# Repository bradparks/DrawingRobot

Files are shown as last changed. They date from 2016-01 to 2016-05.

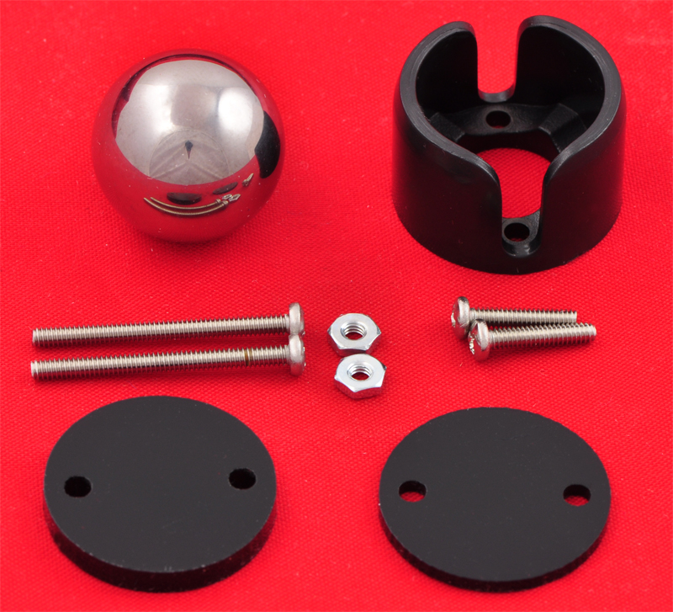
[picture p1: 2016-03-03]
OpenSCAD/pezzi/ballcaster/ball caster pololu 955.jpg

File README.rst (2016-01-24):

DrawingRobot
======


.. :scale: 50 %
.. :alt: DrawingRobot logo

Progetto per lo sviluppo di piccoli robot controllabili via bluetooth in grado di muoversi e disegnare sul piano in cui si muovono

`Overview <http://dev.hacklabterni.org/projects/drawrobot2015/>`_

`Wiki <http://dev.hacklabterni.org/projects/drawrobot2015/wiki>`_

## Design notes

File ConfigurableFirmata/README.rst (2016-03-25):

ConfigurableFirmata
======

`ConfigurableFirmata LastVersion <https://github.com/hacklabterni/ConfigurableFirmata>`_

`ConfigurableFirmata Tested <http://dev.hacklabterni.org/attachments/download/1256/ConfigurableFirmata-master.zip>`_

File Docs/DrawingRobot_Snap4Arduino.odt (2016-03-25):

Importare il progetto tramite la voce di menù Import:

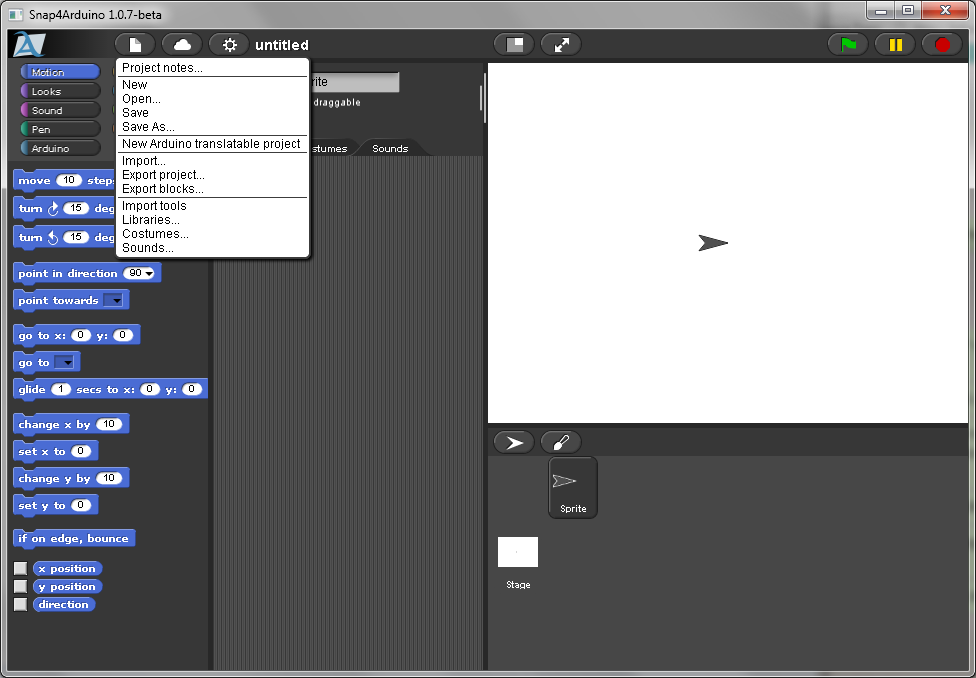
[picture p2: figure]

Selezionando l'ultima versione presente su GitHub: https://github.com/hacklabterni/DrawingRobot/blob/master/Snap4Arduino/DrawingRobot.xml

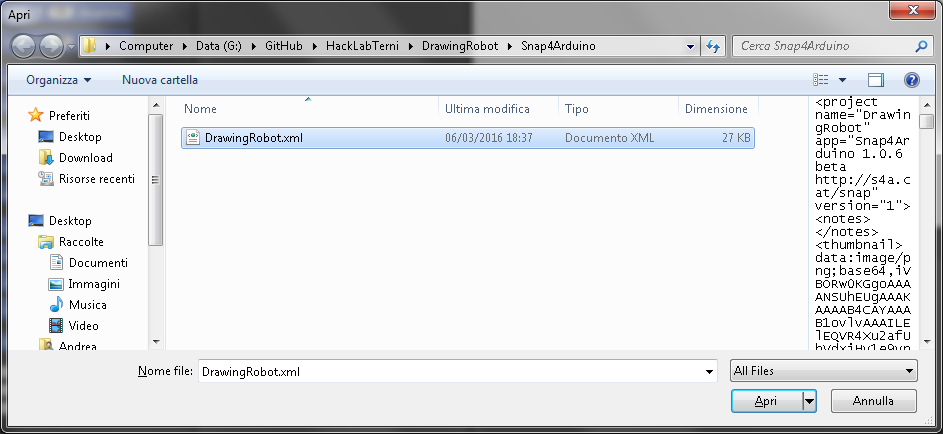
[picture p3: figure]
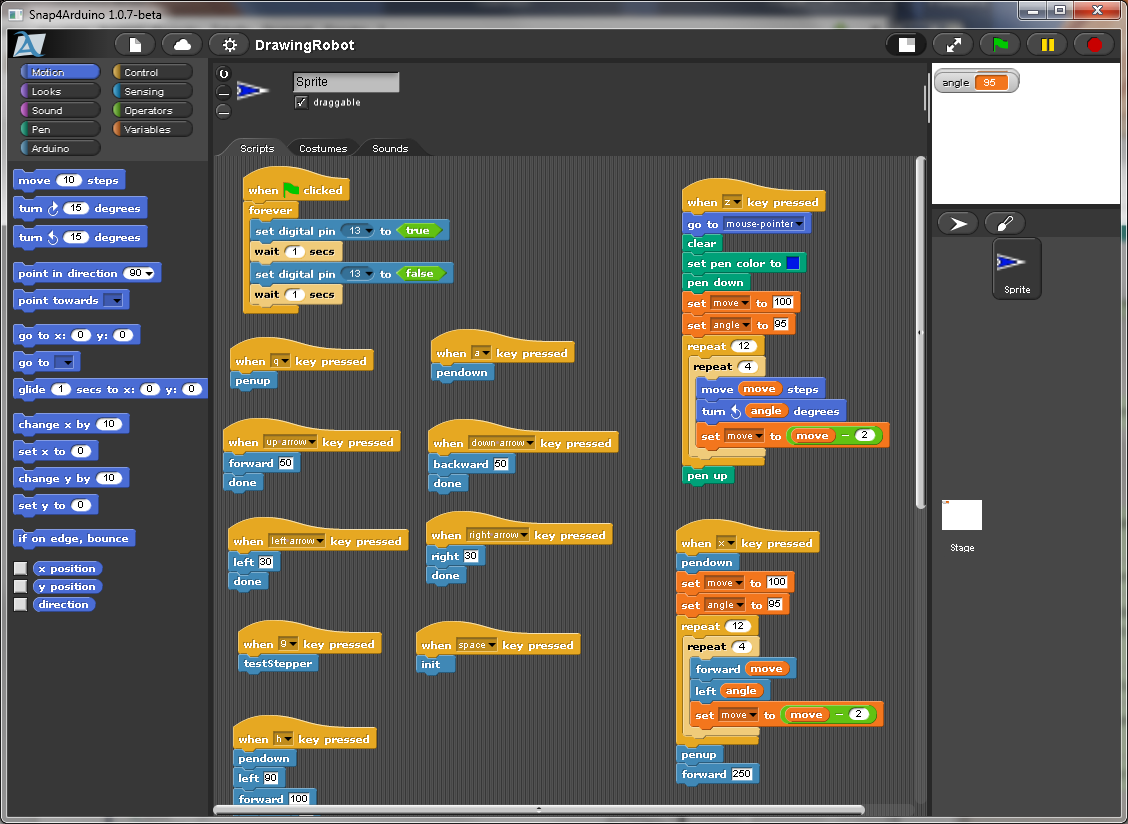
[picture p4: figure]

Se il processo di importazione è avvenuto correttamente si otterrà la seguente schermata:

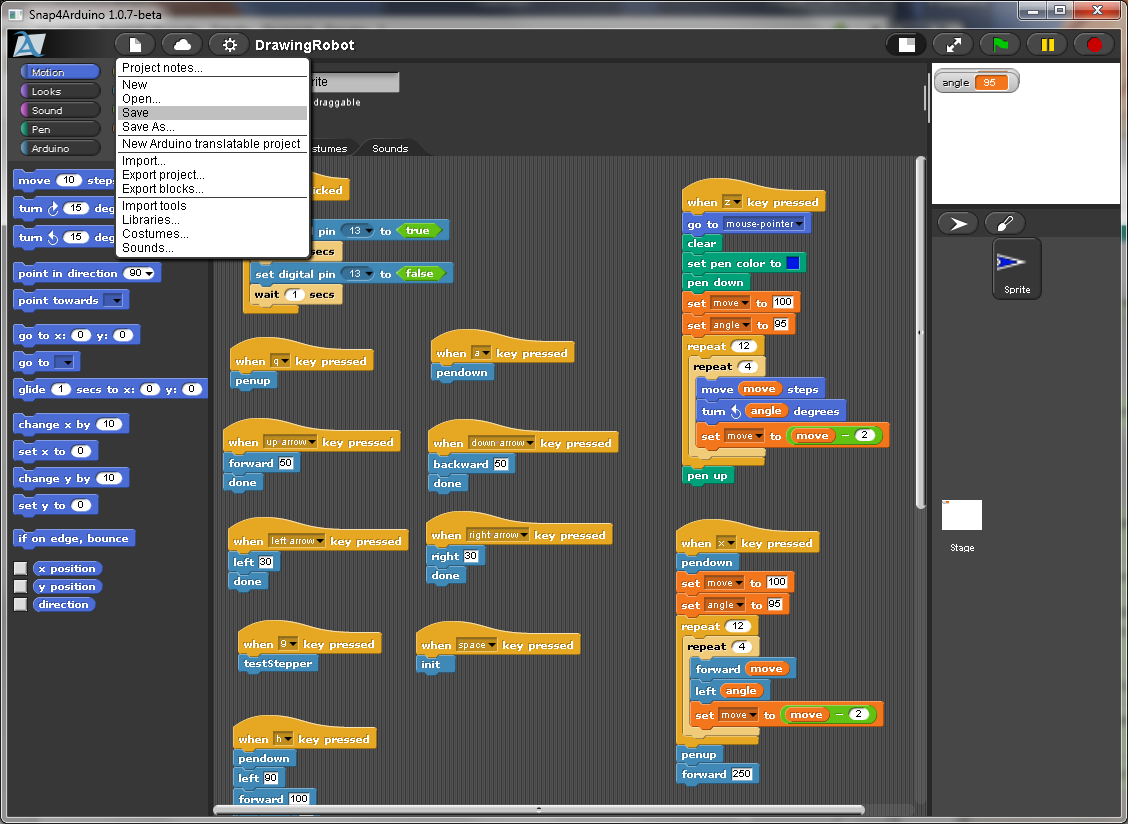
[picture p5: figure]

Salvare il progetto tramite la voce di menù Save, in questo modo si potrà riaprire il progetto stesso tramite Open (senza ripetere l'operazione precedente di import)

Spostarsi nei blocchi di Arduino

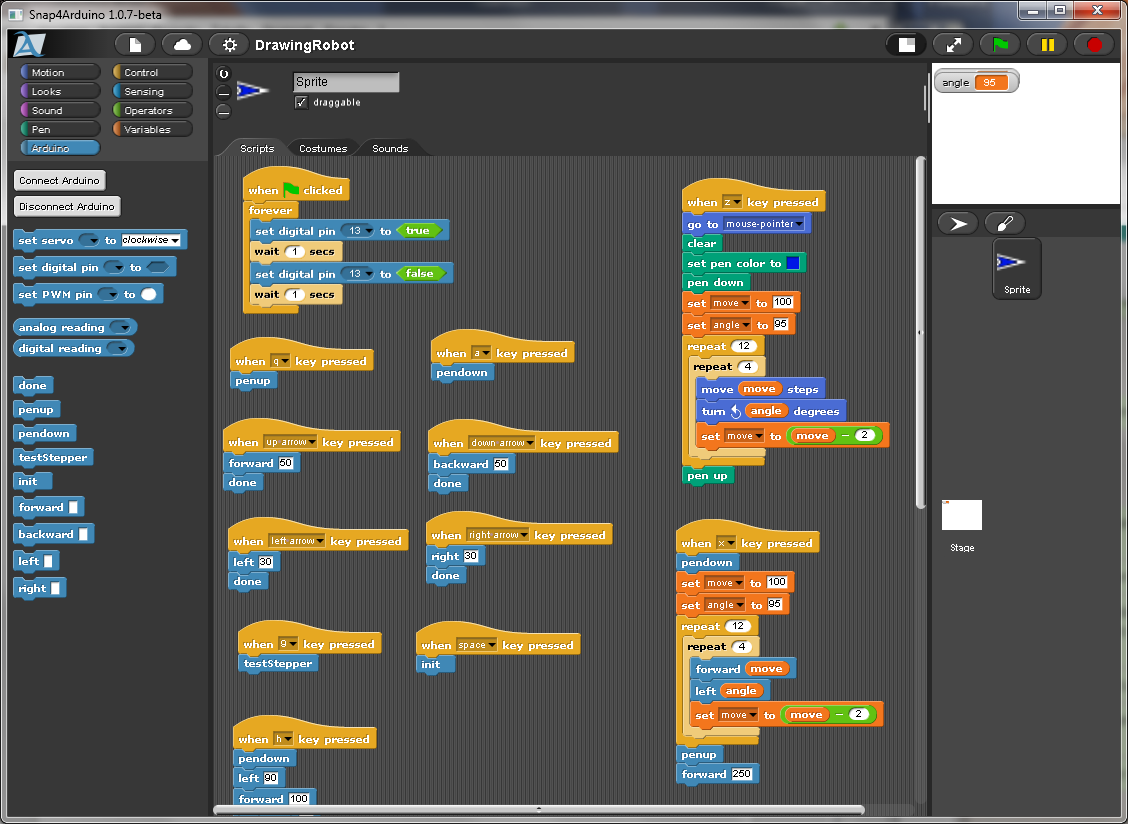
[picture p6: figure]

Premere il pulsante Connect Arduino selezionando la porta corretta

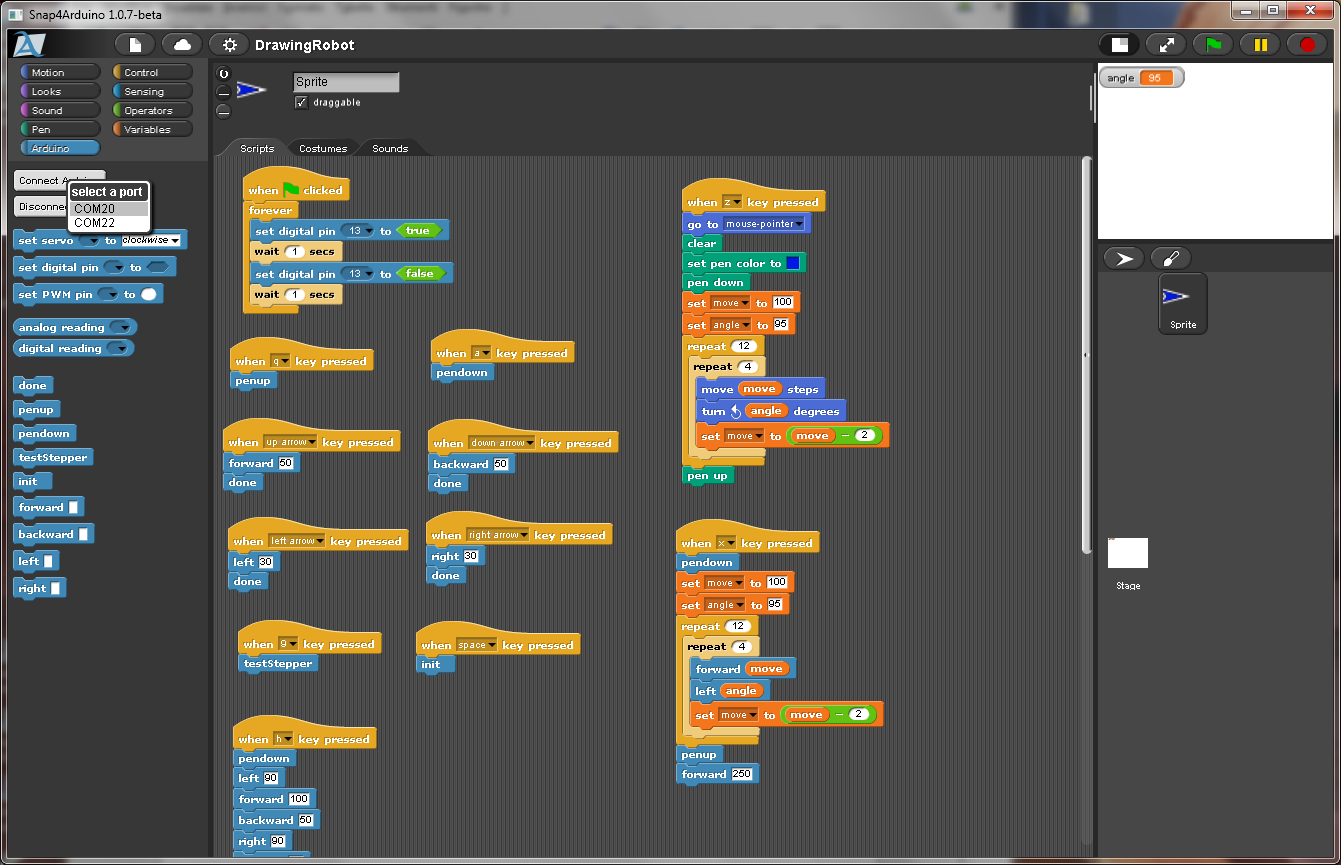
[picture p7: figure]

Attendere l'instaurarsi della connessione

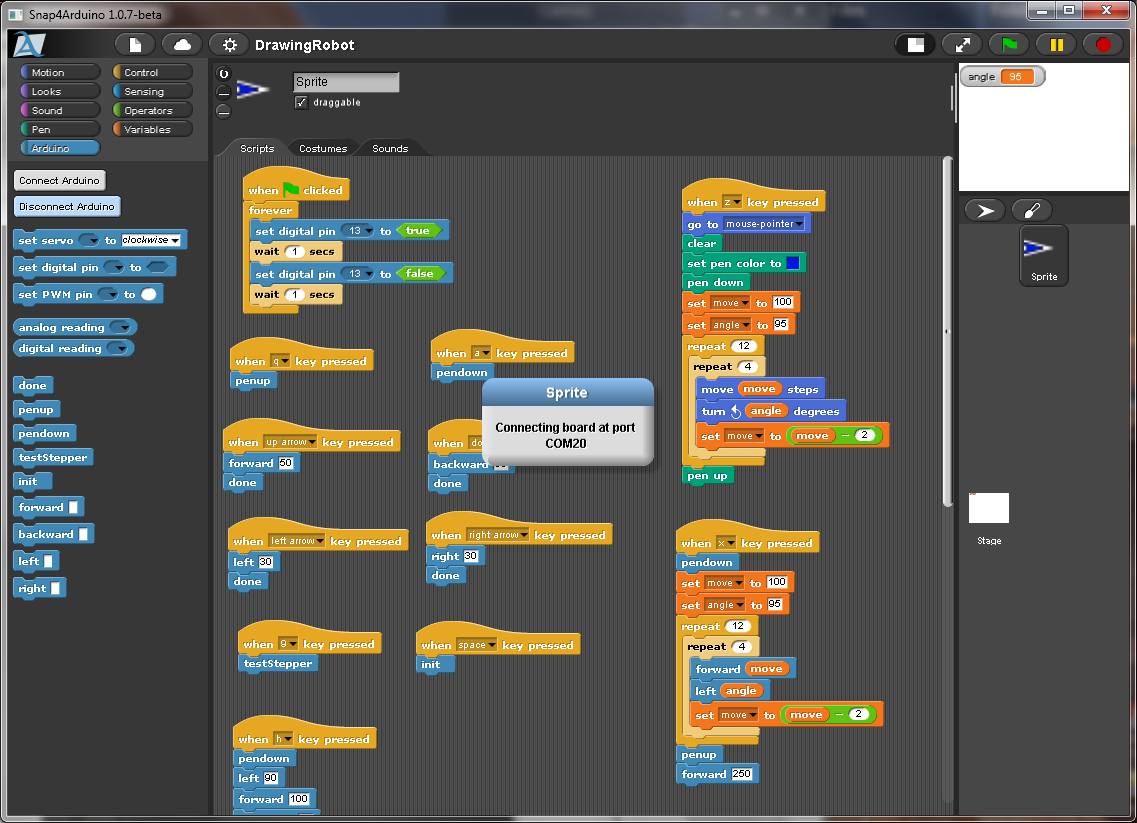
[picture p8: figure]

Connessione avvenuta con successo, il Drawing Robot è ai vostri comandi

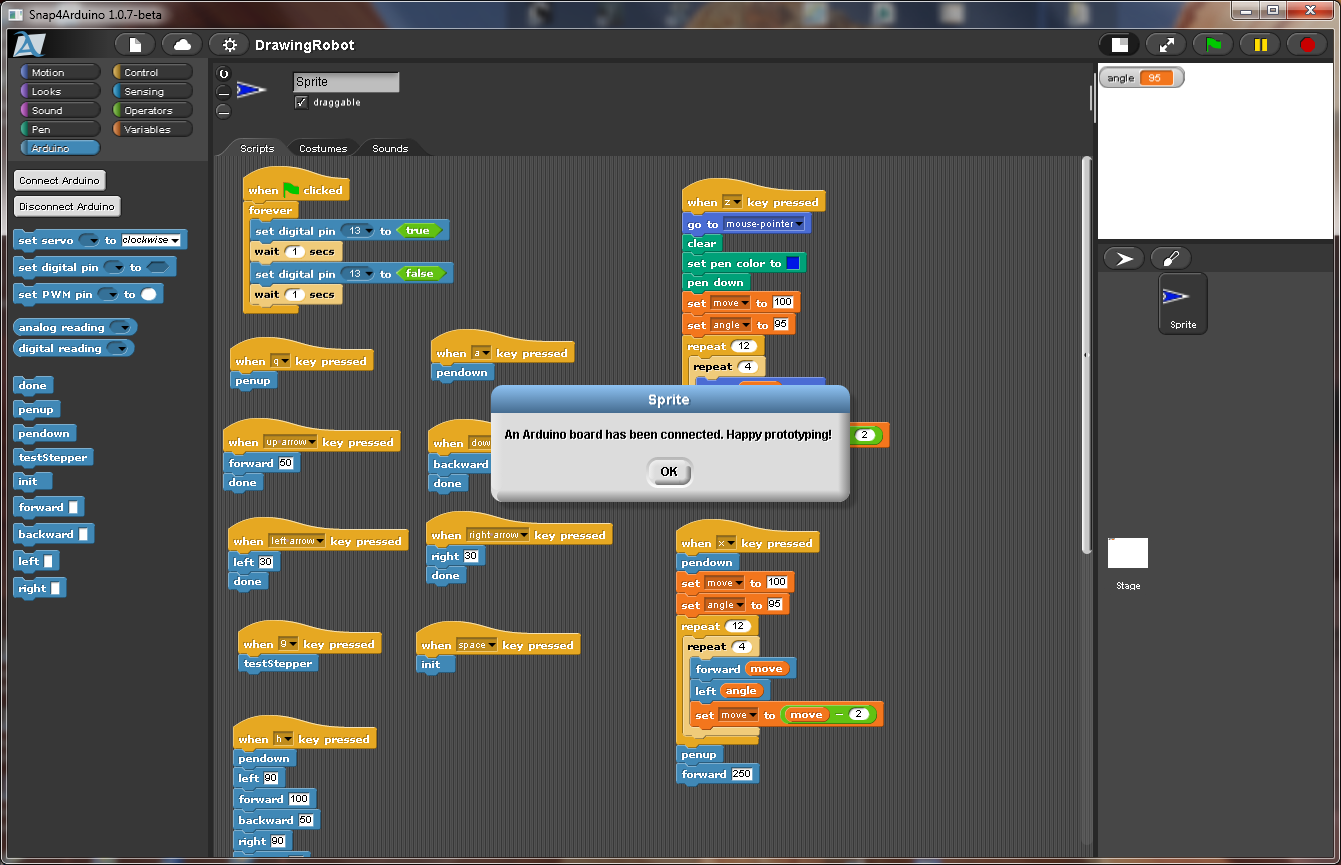
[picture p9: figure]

Come prima cosa occorre eseguire il blocco init di inizializzazione tramite il tasto space della tastiera.

Da questo momento si possono inviare tutti i seguenti comandi al Drawing Robot:

1. penup
2. pendown
3. forward (x)
4. backward (x)
5. left (a)
6. right (a)
7. done

dove la x è espressa in mm e la a in gradi

Importante alla fine di ogni insieme di comandi è consigliabile far eseguire il blocco done che ha la funzione di sbloccare i motori.

Note: Non instaurare la connessione con Arduino se prima non si è caricato/importato il programma DrawingRobot in Snap4Arduino

Troubleshooting:

1. Connect Arduino non instaura correttamente la connesione:
  a. Assicurarsi di aver eseguito il pairing con il bluetooth
  b. Provare altra porta
  c. Riavviare il DrawingRobot (tramite apposito interruttore) e poi chiudere e riaprire il programma Snap4Arduino

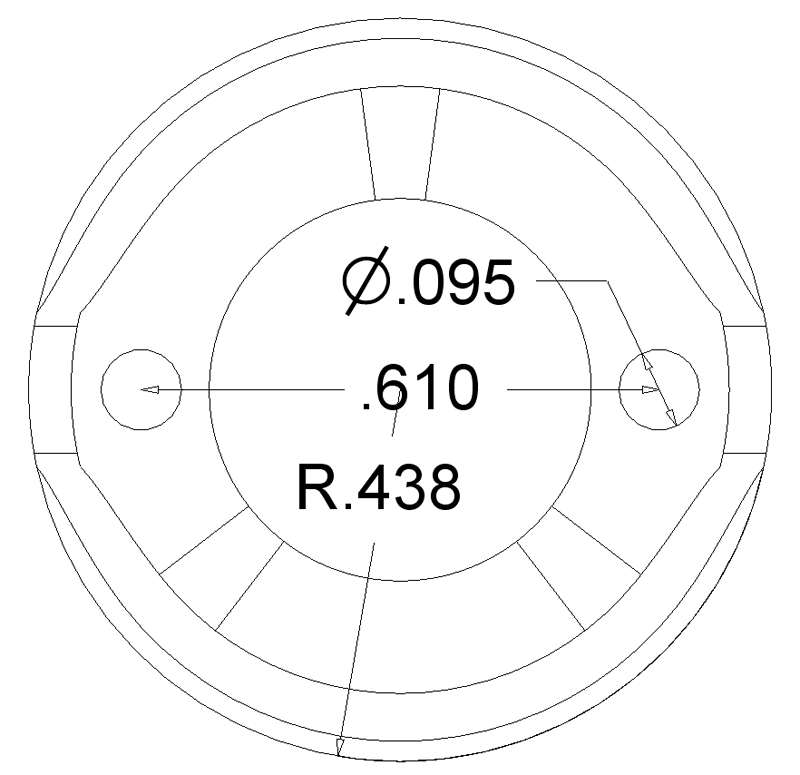
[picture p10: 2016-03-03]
OpenSCAD/pezzi/ballcaster/ball caster pololu 955 misure2.jpg

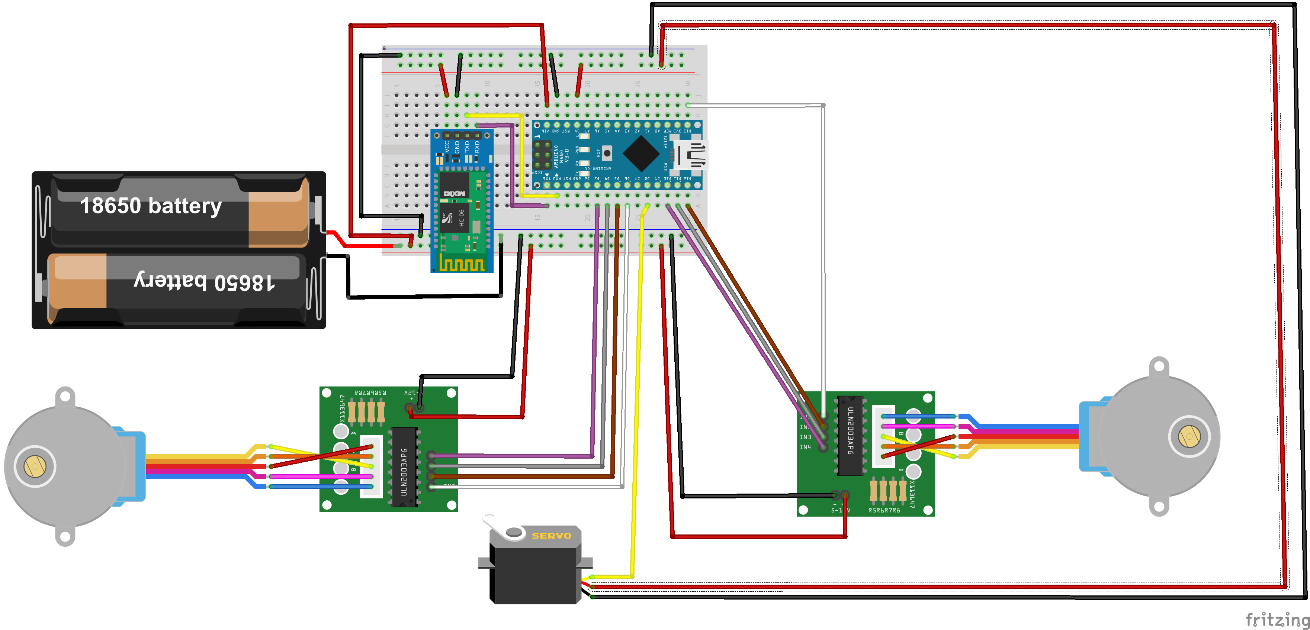
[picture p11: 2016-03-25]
Fritzing/DrawingRobot_2x18650_bb.png

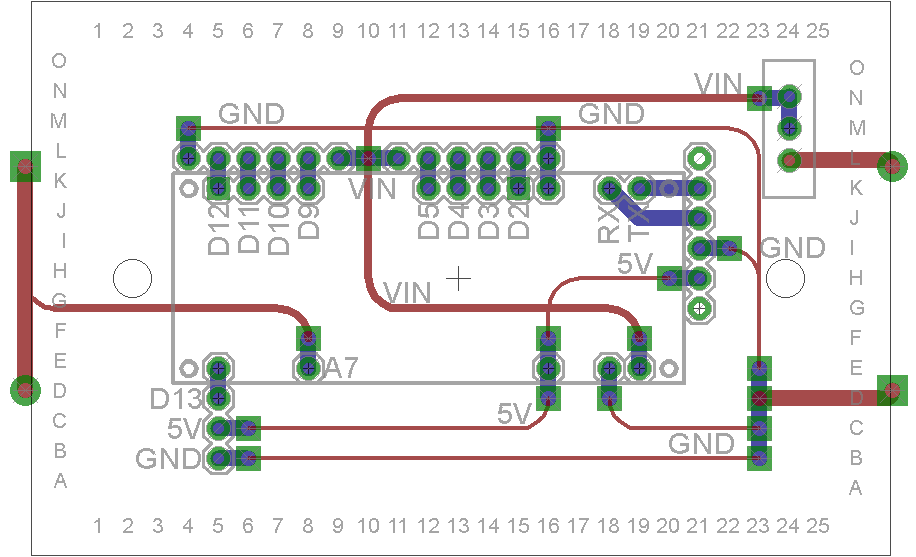
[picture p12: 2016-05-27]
Eagle/millefori.png

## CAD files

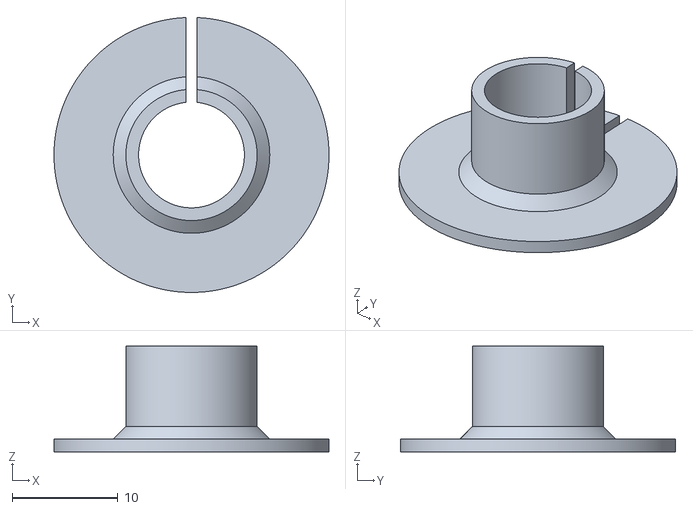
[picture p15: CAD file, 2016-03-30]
da stampare/Pen_Collar2.stl
26.0 x 26.0 x 10.0

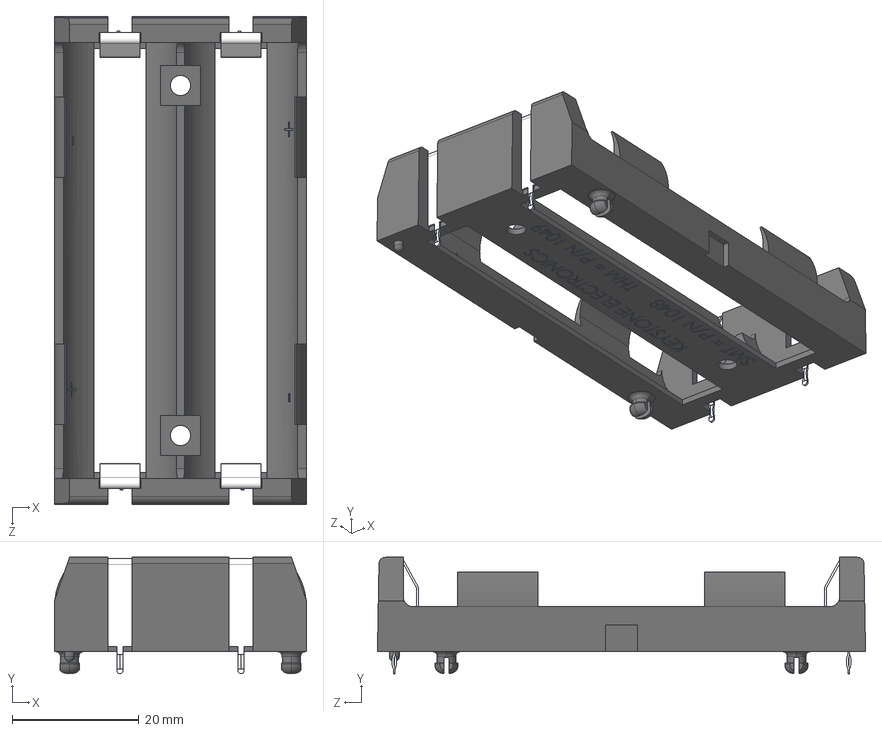
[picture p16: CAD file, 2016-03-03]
OpenSCAD/pezzi/elettronica/batt/keystone-PN1049.stp
39.8 x 18.4 x 77.1 mm

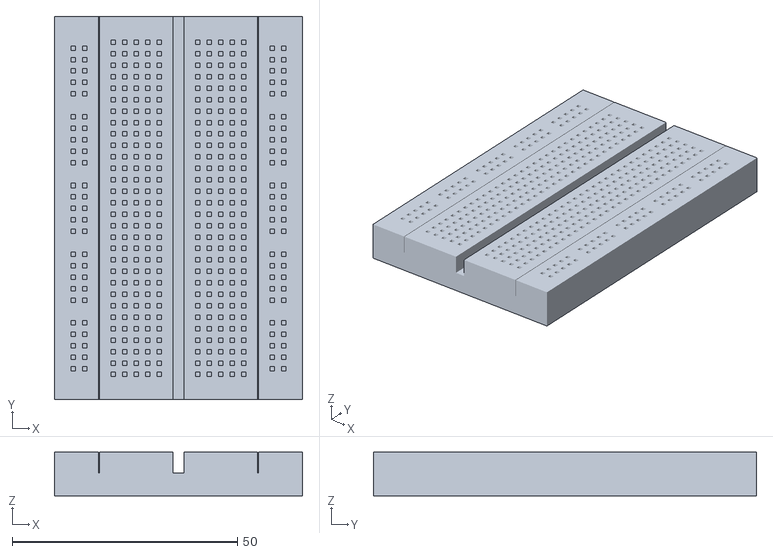
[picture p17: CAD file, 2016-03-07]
OpenSCAD/pezzi/protoboard.stl
55.0 x 85.0 x 9.70

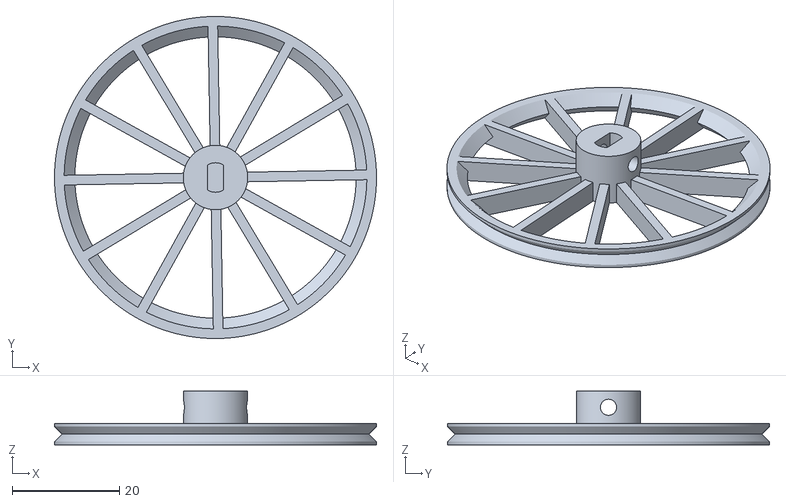
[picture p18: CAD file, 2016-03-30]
da stampare/12wheelNew.stl
60.0 x 60.0 x 10.0

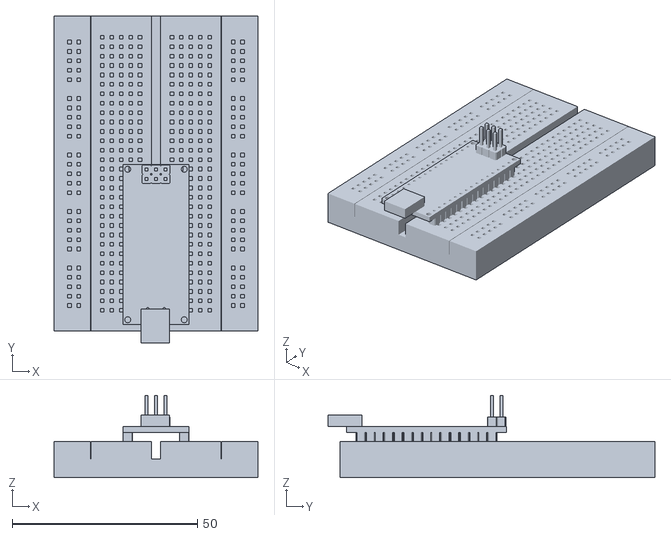
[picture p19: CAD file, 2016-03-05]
OpenSCAD/pezzi/protoboard/protoboard_Arduino.stl
55.0 x 88.3 x 22.2

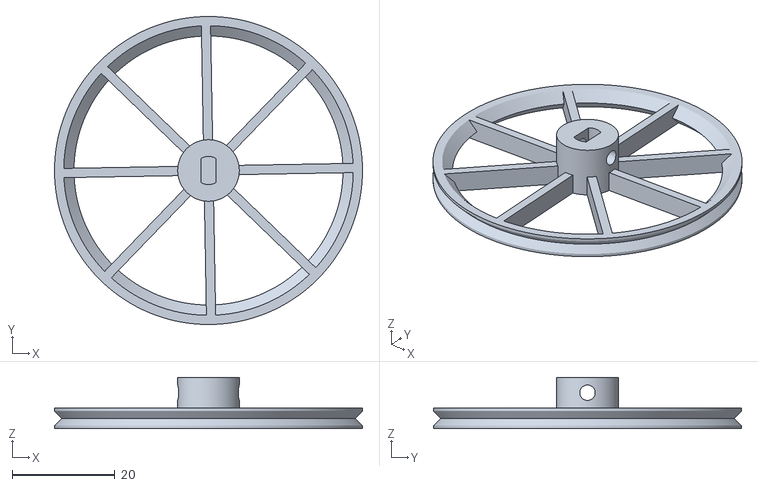
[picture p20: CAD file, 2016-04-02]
OpenSCAD/ruota8raggi.stl
60.0 x 60.0 x 10.0

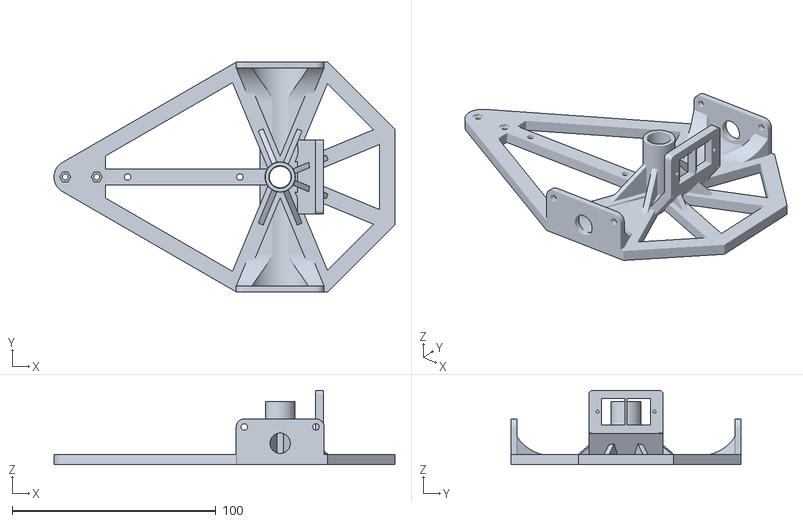
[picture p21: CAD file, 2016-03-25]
OpenSCAD/ottagono_triangolo_barreUguali.stl
167.5 x 112.9 x 36.5

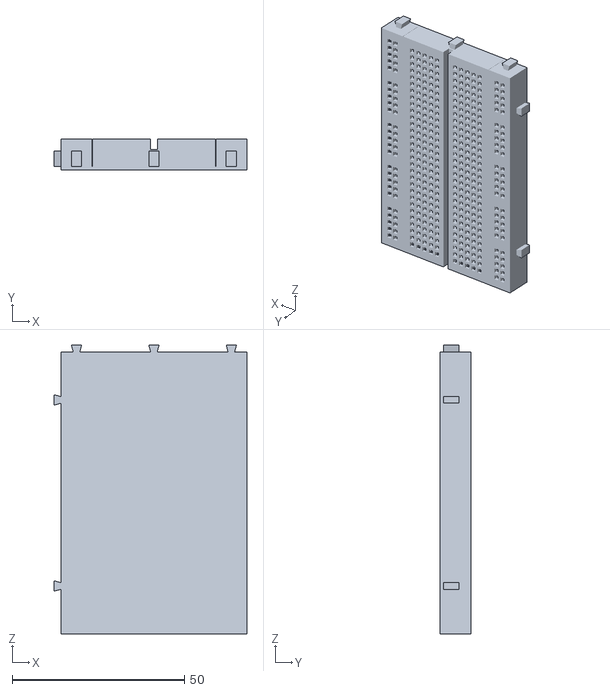
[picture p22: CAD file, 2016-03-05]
OpenSCAD/pezzi/protoboard/OLDprotoboard.stl
56.0 x 9.00 x 84.0

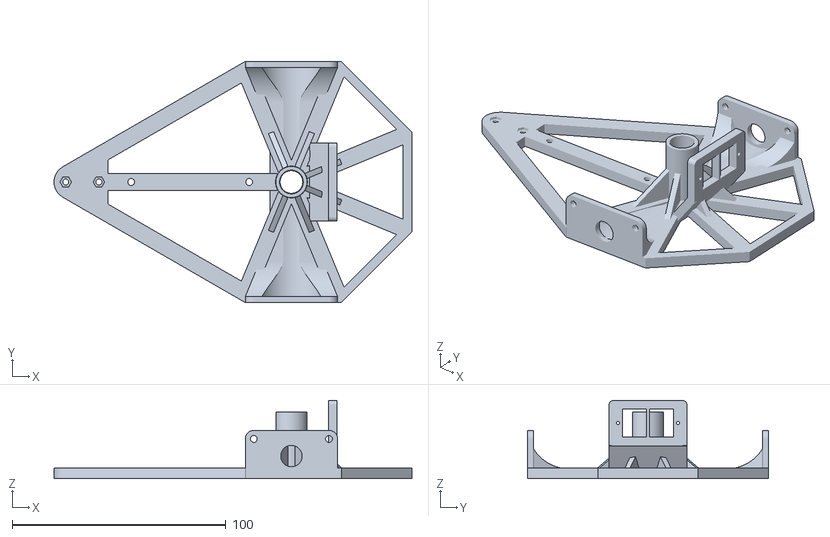
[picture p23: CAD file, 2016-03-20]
OpenSCAD/ottagono_triangoloSmussato.stl
167.5 x 112.9 x 36.5

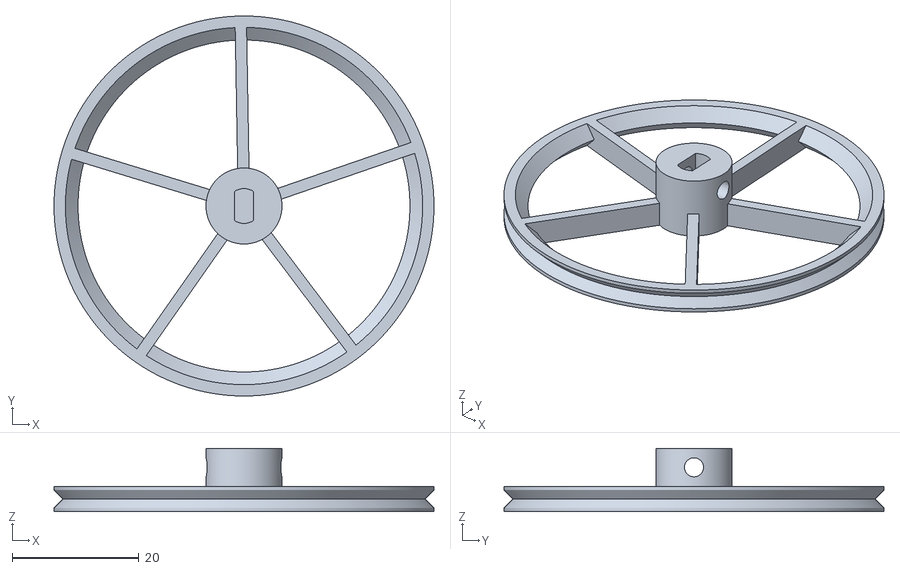
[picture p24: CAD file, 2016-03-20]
OpenSCAD/ruota5raggi.stl
60.0 x 60.0 x 10.0

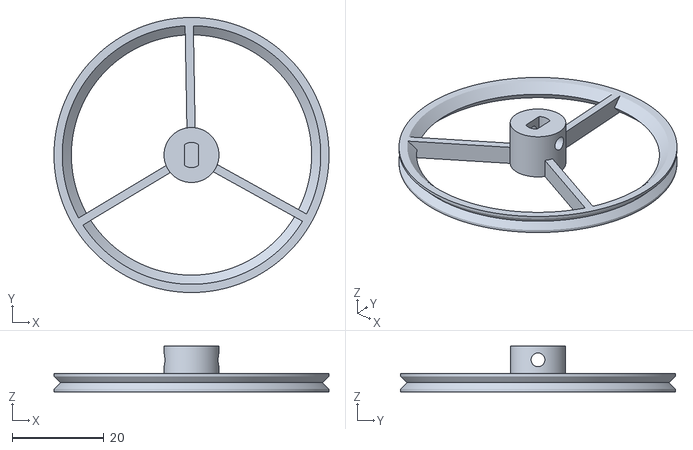
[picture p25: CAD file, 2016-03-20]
OpenSCAD/ruota3raggi.stl
60.0 x 60.0 x 10.0

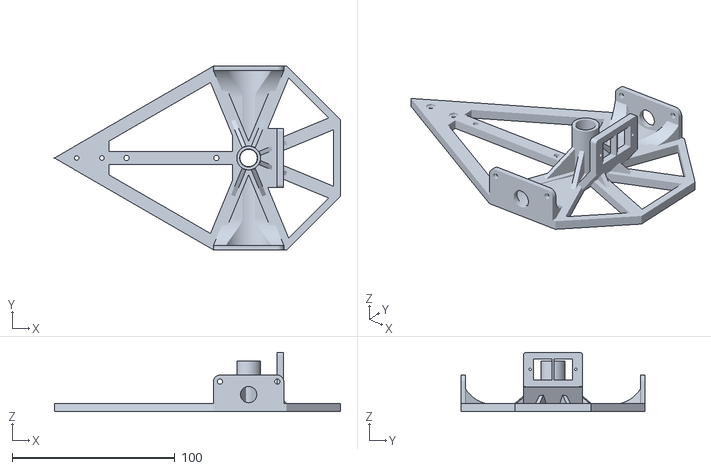
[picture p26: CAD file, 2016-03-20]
OpenSCAD/ottagono_triangolo.stl
175.6 x 112.9 x 36.5

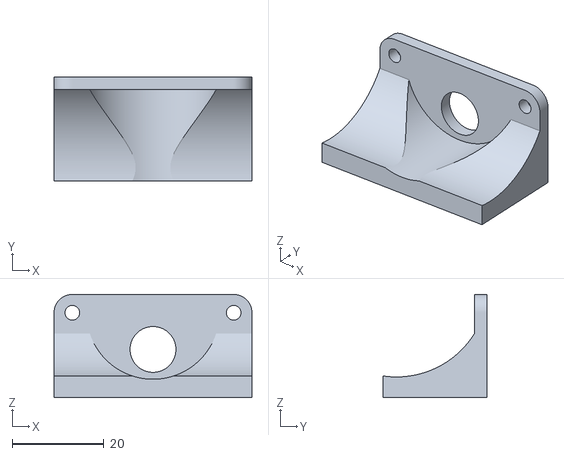
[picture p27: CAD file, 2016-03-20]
OpenSCAD/ruota_motore2.stl
43.2 x 22.8 x 22.5

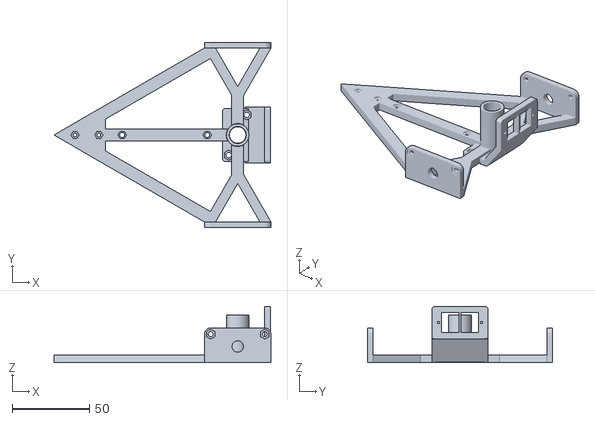
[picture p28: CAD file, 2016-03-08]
OpenSCAD/union_stampabile_servo_da_mod.stl
140.8 x 120.0 x 36.5

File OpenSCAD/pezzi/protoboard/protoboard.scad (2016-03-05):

mx=[[1,0,0],[0,0,0]]; //mirror X
x=55;
y=85;
z=9.7;
passo=2.54;

difference() {
    translate([-x/2,0,0]) cube([x,y,z]);
    union() {
        translate([-passo/2,0,passo*2]) cube([passo,y,z-passo*2]);
        for (i=mx) mirror(i) {
            translate([x/2-10,0,passo*2]) cube([0.2,y,z-passo*2]);
            for(a=[1:1:5], b=[1:1:30]) translate([a*passo+passo/2,b*passo+passo,passo*2]) cube([1,1,z-passo*2]);
            for(a1=[8,9], b1=[1,2,3,4,5, 7,8,9,10,11, 13,14,15,16,17, 19,20,21,22,23, 25,26,27,28,29]) translate([a1*passo,b1*passo+passo*3/2,passo*2]) cube([1,1,z-passo*2]);
        }
    }
}

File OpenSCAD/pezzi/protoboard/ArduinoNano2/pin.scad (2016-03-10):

module pin(n){
    millis= 0.0254;
    pin=    30*millis;
    pinH=   450*millis;
    space=  100*millis;
    cut=    10*millis;
    mXY=[   [0,0,0], 
            [0,1,0],
            [1,0,0],
            [1,1,0]]; //mirror XY
for (x=[0:1:n-1], y=[0:1:0]) translate([x*2.54,y*2.54,0]) {
   
    color("gold")
    translate ([-pin/2,-pin/2,-120*millis]) cube([pin,pin,pinH]);    
    color("gray") 
    difference(){
        translate(-[space,space]/2) cube([space,space,space]);
//        for (i=mXY) mirror(i) translate([space,space]/2)cylinder(space,cut,cut,$fn=8);
    }
}
}
pin(10);

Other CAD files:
OpenSCAD/Pen_Collar2.stl
OpenSCAD/pezzi/protoboard/protoboard.stl
OpenSCAD/pezzi/elettronica/batt/batt.stl
OpenSCAD/pezzi/protoboard/protoboard_light.scad
OpenSCAD/pezzi/protoboard/ArduinoNano2/pinF.scad
OpenSCAD/Chassis_Trinket.scad
OpenSCAD/Pen_Holder2.scad
OpenSCAD/Stepper_Bracket2.scad
OpenSCAD/Tutto_Michele.scad
OpenSCAD/cuore.scad
OpenSCAD/hexagon.scad
OpenSCAD/ottagono_triangolo.scad
OpenSCAD/pezzi/ballcaster/ballcaster.scad
OpenSCAD/pezzi/batt_electronics.scad
OpenSCAD/pezzi/elettronica/ArduinoNanoXY/ArduinoNanoXY.scad
OpenSCAD/pezzi/elettronica/ArduinoNanoXY/pinFxy.scad
OpenSCAD/pezzi/elettronica/ArduinoNanoXY/pinMxy.scad
OpenSCAD/pezzi/elettronica/elettronica.scad
OpenSCAD/pezzi/protoboard/ArduinoNano/pin.scad
OpenSCAD/pezzi/protoboard/ArduinoNano/pinF.scad
OpenSCAD/pezzi/protoboard/ArduinoNano2/ArduinoNano.scad
OpenSCAD/pezzi/protoboard/MILLEFORI.scad
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

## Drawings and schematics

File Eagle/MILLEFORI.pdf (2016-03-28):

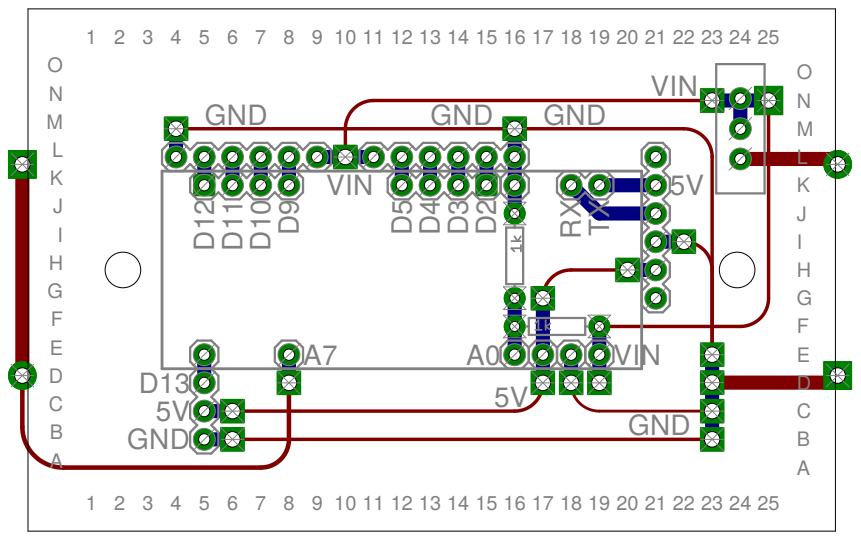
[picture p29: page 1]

D12 D13 TXRXD2 D3 D4 D5 D9 D10 D11 GND VIN 5V A7 A05V VIN GND5V GND GND GND VIN 1 2 3 4 5 6 7 8 9 10 11 12 13 14 15 16 17 18 19 20 21 22 23 24 25 HGFEDCBAONMLKJI HGFEDCBAONMLKJI 1 2 3 4 5 6 7 8 9 10 11 12 13 14 15 16 17 18 19 20 21 22 23 24 25

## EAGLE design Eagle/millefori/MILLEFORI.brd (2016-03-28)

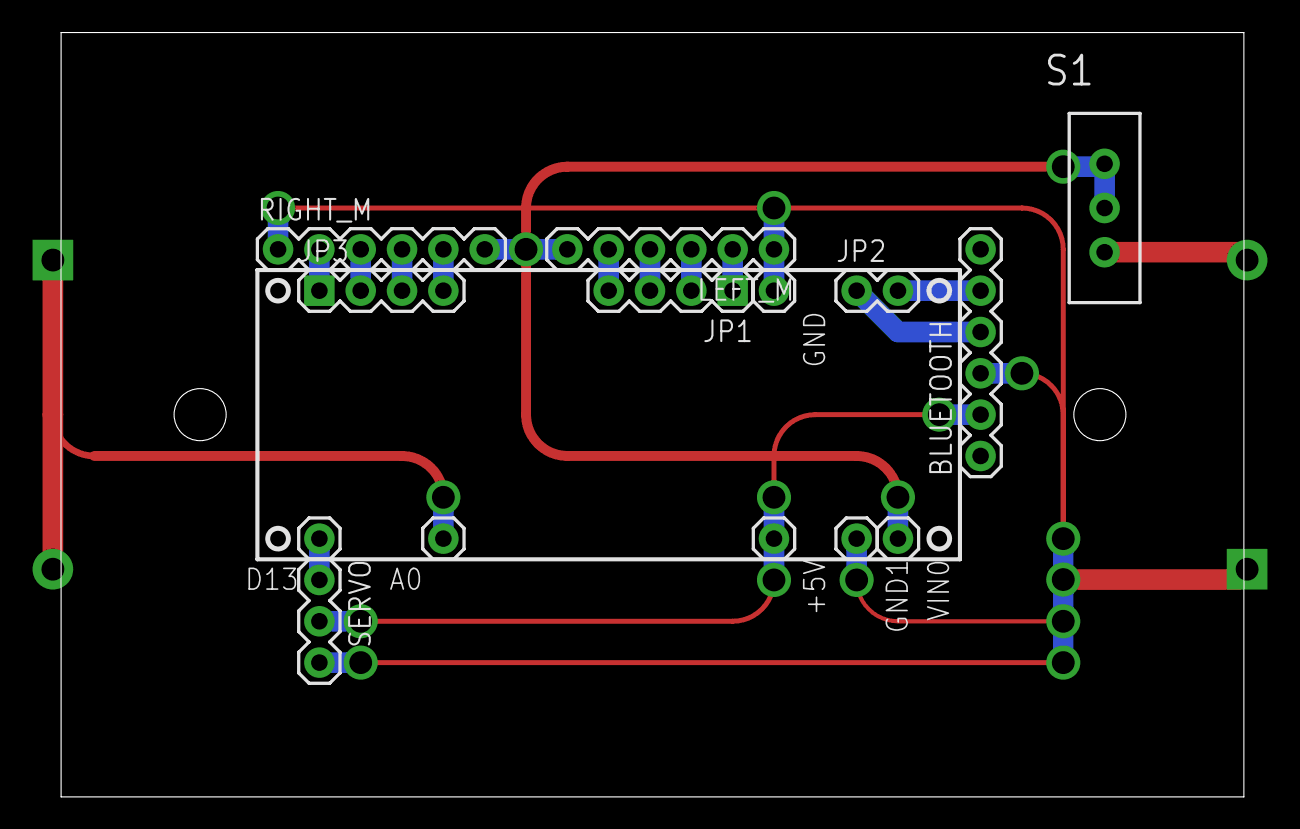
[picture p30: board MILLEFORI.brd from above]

Board: 2 copper layers, 72.7 x 47.0 mm, 15 parts (0 on the bottom side), 16 nets.

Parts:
+5V: 1X01
A0: 1X01
BLUETOOTH: 1X06
D13: 1X01
GND, GND1: 1X01
JP1, JP3: 1X04
JP2: 1X02
LEFT_M: 1X06
RIGHT_M: 1X06
S1: SWITCH-SPDT_LOCK.007S
SERVO: 1X03
U$3: 18650; BATTERY_PACK_18650
VIN0: 1X01

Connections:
+5V: +5V.1, BLUETOOTH.2, SERVO.2
+7,2V: S1.3, U$3.+3.7V_1
A0: A0.1, U$3.+3.7V_2, U$3.GND_1
D0/RX: BLUETOOTH.5, JP2.2
D1/TX: BLUETOOTH.4, JP2.1
D2: JP1.1, LEFT_M.2
D3: JP1.2, LEFT_M.3
D4: JP1.3, LEFT_M.4
D5: JP1.4, LEFT_M.5
D9: JP3.1, RIGHT_M.2
D10: JP3.2, RIGHT_M.3
D11: JP3.3, RIGHT_M.4
D12: JP3.4, RIGHT_M.5
D13: D13.1, SERVO.1
GND: BLUETOOTH.3, GND.1, GND1.1, LEFT_M.1, RIGHT_M.1, SERVO.3, U$3.GND_2
VIN: LEFT_M.6, RIGHT_M.6, S1.1, S1.2, VIN0.1

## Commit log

2016-02-04 First release
    [DrawingRobot.xml]
2016-02-04 change steps_rev
    [DrawingRobot.xml]
2016-02-04 change pin order, add Callback function
    [DrawingRobot.xml]
2016-02-04 fine adjustment
    [DrawingRobot.xml]
2016-02-04 inverted CW and CCW
    [DrawingRobot.xml]
2016-02-04 add acceleration and deceleration
    [DrawingRobot.xml]
2016-03-03 Pezzi usati
    raccolta di .stl .scad. immagini e datasheet dei componenti utilizzati
    [28BYJ_stepper.scad, SG90_servo.scad, SG90_servo_old.scad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]
2016-03-03 Chassis +supporto motori
    [Tutto_Michele.scad]
2016-03-05 quello che va sulla protoBoard
    [ArduinoNano.scad, OLDprotoboard.stl, pin.scad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]
2016-03-06 clear old methods
    [DrawingRobot.xml]
2016-03-07 pezzi finiti lavori in corso
    [28BYJ_stepper.scad, ArduinoNano.scad, ballcaster.scad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]
2016-03-08 manca nuovo supporto servo
    union stampabile da testare
    [Stepper_Bracket2.scad, ruota_motore.scad, union.scad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]
2016-03-16 da stampare?
    [ottagono_triangolo.scad]
2016-03-20 barre uguali
    [ottagono_triangolo_barreUguali.stl]
2016-03-23 DrawingRobot 2x18650 New Battery
    [DrawingRobot_2x18650.fzz, DrawingRobot_4xAA.fzz]
2016-03-24 Aggiunto il blocco done al termine del disegno
    [DrawingRobot.xml]
2016-03-25 SCHEMA ELETTRICO
    [MILLEFORI.brd]
2016-03-30 ruote e collatino penna
    [12wheelNew.stl, Pen_Collar2.stl]
2016-04-02 Ruota 8 Raggi + Collare Penna
    [Pen_Collar2.stl, ruota8raggi.stl]

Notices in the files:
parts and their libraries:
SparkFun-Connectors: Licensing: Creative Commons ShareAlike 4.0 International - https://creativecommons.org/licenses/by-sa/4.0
